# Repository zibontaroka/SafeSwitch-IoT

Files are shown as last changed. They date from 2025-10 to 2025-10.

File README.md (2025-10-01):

# ⚡ SafeSwitch-IoT: A Secure IoT-Based Control Handover System for Power Line Maintenance

  
  
  
  

This repository contains the full implementation of an **IoT-based Smart Power Control Handover System** that enhances **lineman safety** in power distribution networks.  
The system introduces a **formalized handover protocol** where Operators can delegate control of electrical zones/feeders to Linemen, ensuring safe maintenance by preventing accidental re-energization.

---

## 📑 Table of Contents
- [Overview](#-overview)
- [Key Features](#-key-features)
- [Technology Stack](#️-technology-stack)
- [Hardware and PCB Design](#-hardware-and-pcb-design)
- [File Structure](#-file-structure)
- [Getting Started](#-getting-started)
- [Usage](#-usage)
- [Contributing](#-contributing)
- [License](#-license)
- [Contact](#-contact)

---

## 📖 Overview
Power line maintenance is inherently dangerous, particularly in developing regions such as **Bangladesh**, where standardized safeguards are limited.  
One major risk arises when Operators unintentionally re-energize lines under maintenance, causing **severe injury or fatality** for Linemen.  

✅ Our proposed solution:  
A **secure IoT-based control handover system** that ensures Operators **cannot switch relays** in a zone once it is handed over to a Lineman.  
Control is restored only after the Lineman safely revokes access via a **PIN-authenticated interface**.

---

## ✨ Key Features
- 🔐 **Secure Control Handover** – Operator-to-Lineman delegation with mutual exclusion.  
- 👤 **Role-Based Access Control (RBAC)** – Enforces permissions per role.  
- ⚡ **Real-Time Communication** – WebSocket-based low-latency updates.  
- 🔑 **PIN-Based Authentication** – Prevents unauthorized relay operations.  
- 📝 **Auditability & Traceability** – Logs every critical action with user ID, timestamp, feeder/zone.  
- 📈 **Modular & Scalable** – Easily extendable for more devices/zones.  

---

## ⚙️ Technology Stack
**Backend:** Node.js · Express.js · PostgreSQL · WebSocket  
**Frontend:** HTML · CSS · JavaScript  
**Hardware:** ESP8266 · LM2596 Buck Converter · 2N2222 NPN Transistor · 1N4007 Diode · Relays  

---

## 🖥️ Web Application Interface

### Operator Dashboard
Centralized control center for system operators to monitor and manage power distribution network.

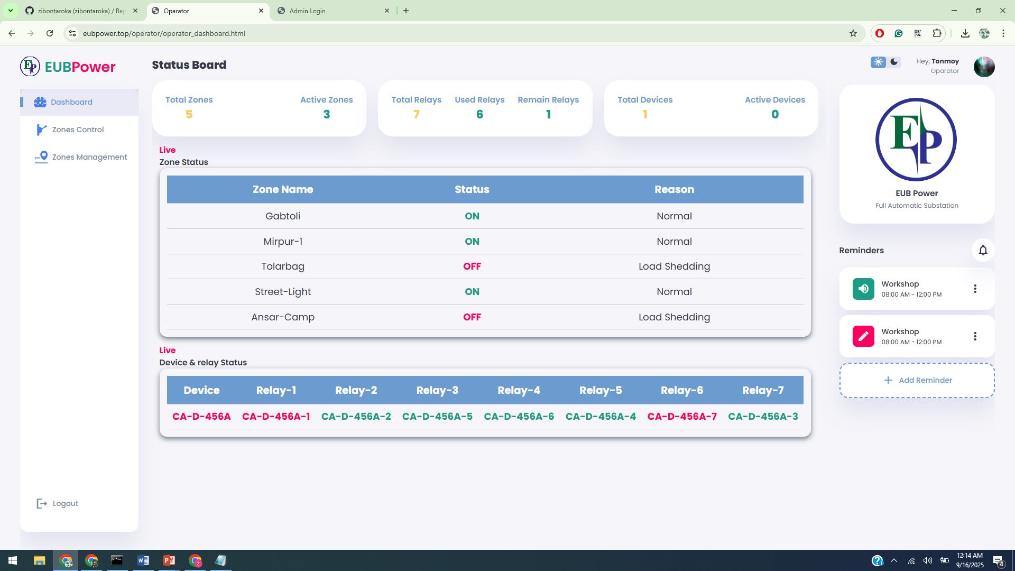
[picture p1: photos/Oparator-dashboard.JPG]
Operator Dashboard


**Key Functionalities:**
- 📊 **Real-time Monitoring** - Live status of all feeders and zones
- 🔄 **Control Handover** - Safe delegation to linemen for maintenance
- 🚨 **Emergency Override** - Critical situation management
- 📈 **System Analytics** - Performance metrics and usage statistics
- 👥 **User Management** - Lineman assignment and role management

**Interface Components:**
1. **Sidebar Navigation** - Quick access to different sections
2. **Dashboard Overview** - System-wide status at a glance  
3. **Feeder Control Panel** - Individual zone management
4. **Handover History** - Audit trail of all control transfers
5. **Alert System** - Real-time notifications and warnings

### Lineman Dashboard
Secure, PIN-protected interface for field technicians during maintenance operations.

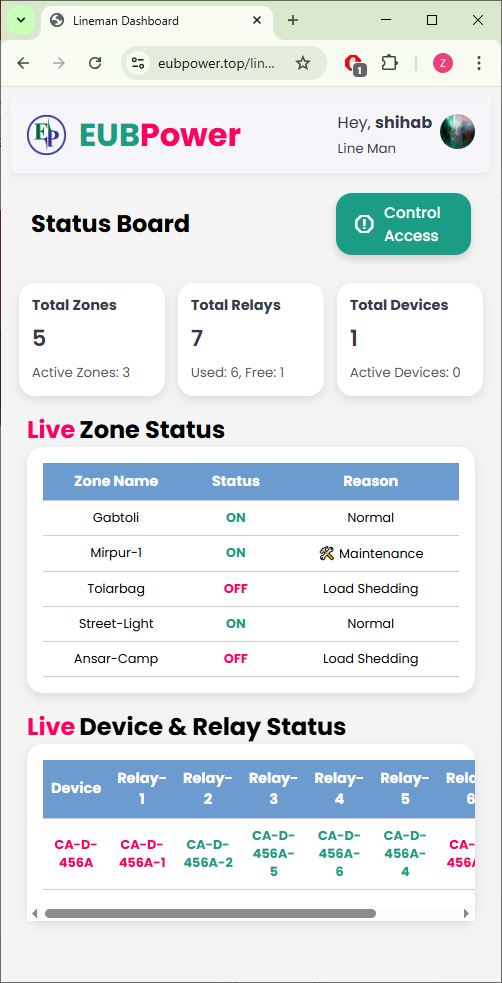
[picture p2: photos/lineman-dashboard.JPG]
Lineman Dashboard


**Key Functionalities:**
- 🔐 **PIN Authentication** - Secure access to assigned zones
- ⚡ **Relay Control** - Direct control over circuit breakers
- 📱 **Mobile-Friendly** - Optimized for field use
- 🔄 **Status Sync** - Real-time synchronization with backend
- ✅ **Safety Lock** - Prevents accidental operations

**Security Features:**
- Session timeout after inactivity
- PIN-based re-authentication required
- Control limited to assigned zones only
- Audit log of all operations
- Emergency stop functionality

### Workflow Demonstration
**Control Handover Process:**
1. Operator initiates handover from their dashboard
2. Lineman receives notification and enters PIN
3. Control transfers to lineman (operator access locked)
4. Lineman performs maintenance operations
5. Lineman revokes control after completion
6. Operator regains full control automatically

---

## 🔧 Hardware and PCB Design

The **ESP8266 control module** manages up to **7 relays** for breaker/switch control.  
It authenticates with the backend and executes Operator/Lineman commands securely.  

### Relay Control Module
- Authentication with backend  
- Relay switching via GPIO  
- Real-time state reporting  

**Schematic Diagram:**  
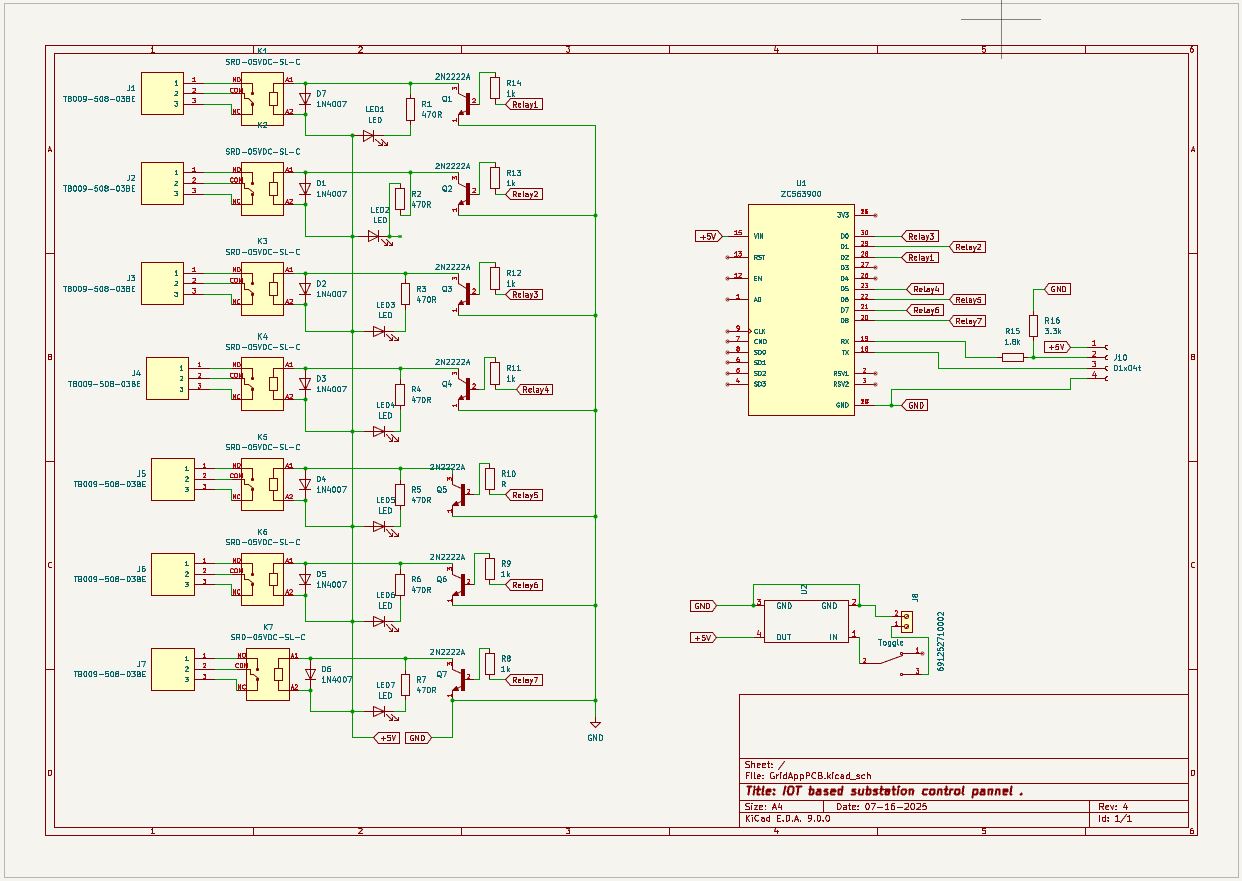
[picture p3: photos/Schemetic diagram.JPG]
Schematic Diagram
  

**PCB Layout:**  
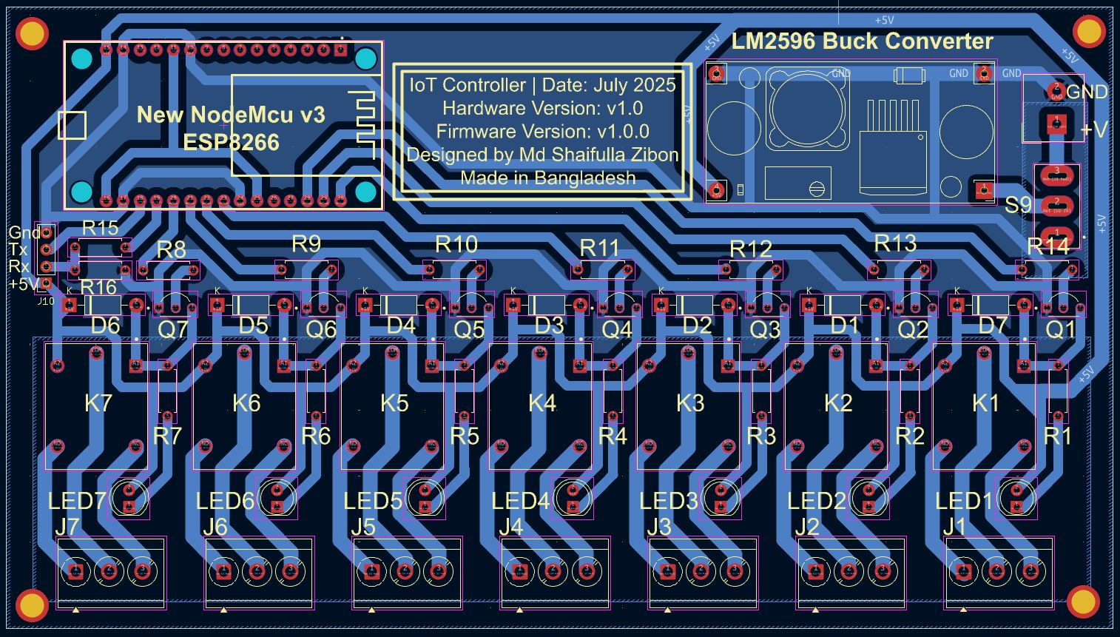
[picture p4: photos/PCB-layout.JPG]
PCB Layout
  

🔗 KiCad project & Gerber files are in the [`PCB_design/`](./PCB_design/) directory.  

---

## 📂 File Structure
```

smart-power-handover-system/
├── database/        # PostgreSQL backup (powergrid\_backup.sql)
├── firmware/        # ESP8266 Arduino firmware
├── PCB\_design/      # Hardware design (KiCad + Gerber)
├── photos/          # PCB & schematic images
├── web\_app/         # Web application (frontend + backend)
├── admin/       # Admin dashboard & user management
├── operator/    # Operator control dashboard
├── lineman/     # Lineman PIN-secured dashboard
├── viewer/      # Viewer-only monitoring UI
├── backend/     # Node.js backend (Express + WebSocket)
├── css/         # Stylesheets
├── js/          # Frontend JS logic
└── images/      # UI assets/icons

```

---

## 🚀 Getting Started

### Prerequisites
- [Node.js](https://nodejs.org/) (>= 18.x)  
- [PostgreSQL](https://www.postgresql.org/)  

### Installation

1. **Clone the repository:**
   ```bash
   git clone https://github.com/zibontaroka/SafeSwitch-IoT.git
   cd smart-power-handover-system/web_app/backend
   ```

2. **Install dependencies:**
   ```bash
   npm install
   ```

3. **Set up the database:**
   - Create a PostgreSQL database
   - Import the backup:
     ```bash
     psql -U your_user -d your_db -f ../../database/powergrid_backup.sql
     ```

4. **Configure environment variables:**
   Create `.env` file in `web_app/backend/` directory with:
   ```env
   DB_USER=your_db_user
   DB_HOST=your_db_host
   DB_DATABASE=your_db_name
   DB_PASSWORD=your_db_password
   DB_PORT=your_db_port
   JWT_SECRET=your_jwt_secret
   ```

5. **Start the server:**
   ```bash
   npm start
   ```

---

## 📖 Usage (Control Workflow)

1. **Initiation** → Operator selects feeder/zone & assigns to a Lineman.
2. **Delegation** → Zone marked as `control_active = TRUE`, blocking Operator actions.
3. **Execution** → Lineman controls relays via PIN-authenticated dashboard.
4. **Revocation** → Lineman revokes control (PIN entry → `control_active = FALSE`).
5. **Restoration** → Operator regains full control.

---

## 🤝 Contributing

Contributions, feature requests, and bug reports are welcome!
Please open an **issue** or submit a **pull request**.

---

## 📄 License

This project currently has **no license**.
(You may add `MIT`, `Apache-2.0`, or another license in a [LICENSE](LICENSE) file.)

---

## 📞 Contact

📧 Md Shaifulla Zibon
🔗 [LinkedIn](https://www.linkedin.com/in/md-shaifulla-zibon/)

---

"# SafeSwitch-IoT"

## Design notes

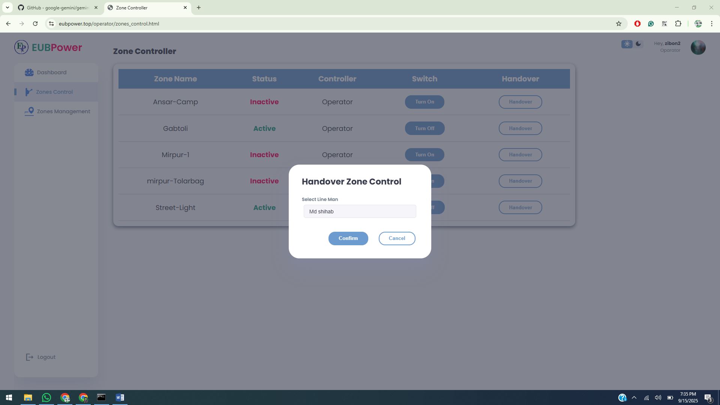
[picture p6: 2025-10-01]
photos/Zone controll and handover page.JPG

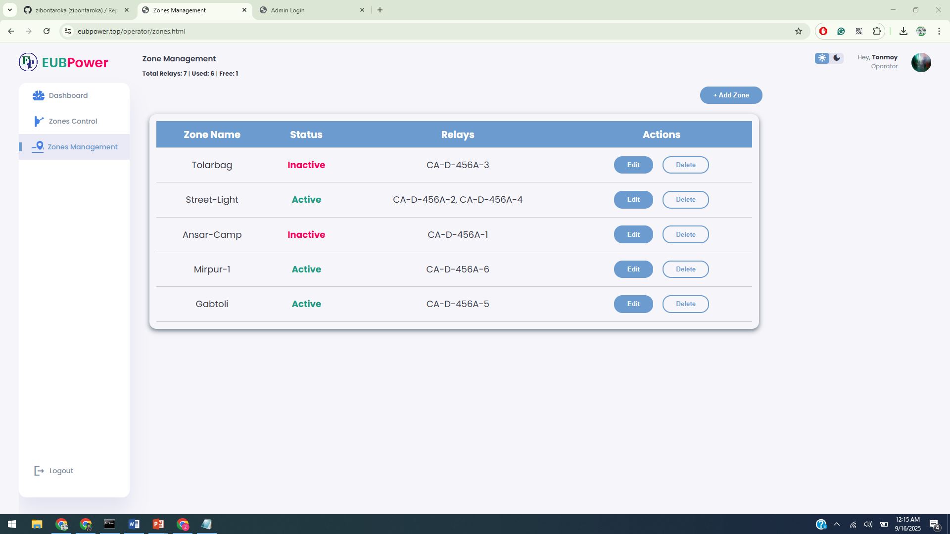
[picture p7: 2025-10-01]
photos/Oparator-zone-management.JPG

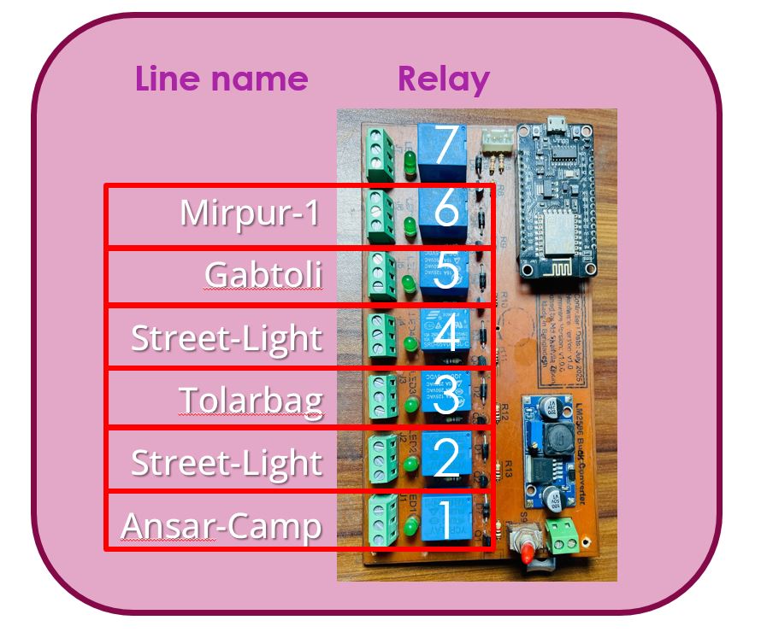
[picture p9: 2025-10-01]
photos/relay and zone configuration.JPG

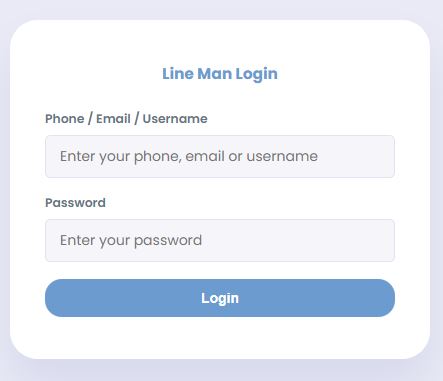
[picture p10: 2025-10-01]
photos/login.JPG

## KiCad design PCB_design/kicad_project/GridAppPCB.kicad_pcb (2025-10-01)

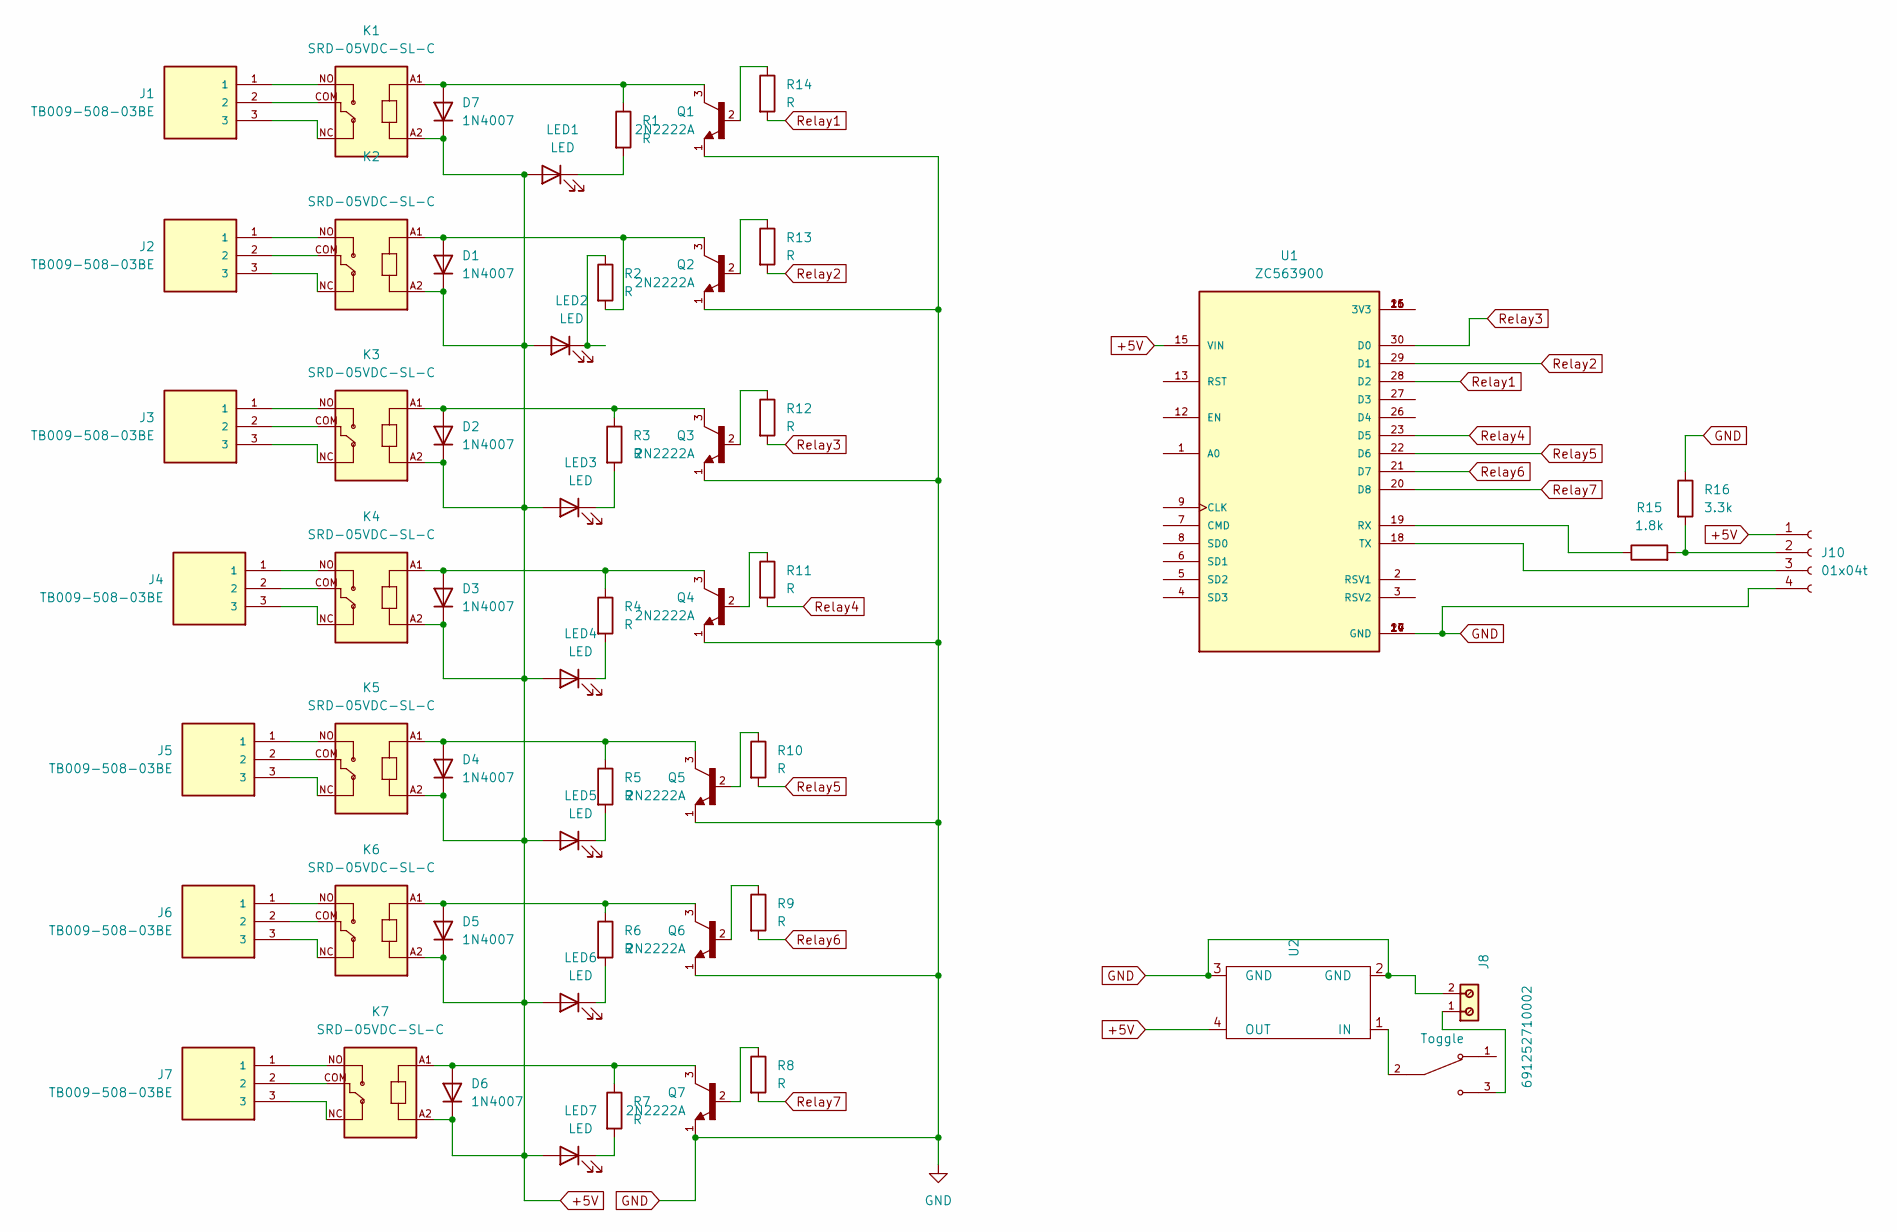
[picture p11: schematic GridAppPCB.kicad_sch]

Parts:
D1, D2, D3, D4, D5, D6, D7: 1N4007; D_DO-41_SOD81_P10.16mm_Horizontal
J1, J2, J3, J4, J5, J6, J7: TB009-508-03BE; TerminalBlock_CUI_TB007-508-03_1x03_P5.08mm_Horizontal
J8: 691252710002; Altech_AK100_1x02_P5.00mm; PART-NUMBER 691252710002
J10: 01x04t; PinSocket_1x04_P2.54mm_Vertical
K1, K2, K3, K4, K5, K6, K7: SRD-05VDC-SL-C; RELAY_SRD-05VDC-SL-C
LED1, LED2, LED3, LED4, LED5, LED6, LED7: LED; LED_D5.0mm
Q1, Q2, Q3, Q4, Q5, Q6, Q7: 2N2222A; TO92254P470H750-3; PARTREV N/A
R1, R2, R3, R4, R5, R6, R7, R8, R9, R10, R11, R12, R13, R14: R; R_Axial_DIN0207_L6.3mm_D2.5mm_P7.62mm_Horizontal
R15: 1.8k; R_Axial_DIN0207_L6.3mm_D2.5mm_P7.62mm_Horizontal
R16: 3.3k; R_Axial_DIN0207_L6.3mm_D2.5mm_P7.62mm_Horizontal
S9: Toggle; SW_100SP1T1B1M1QEH; PARTREV D
U1: ZC563900; MODULE_ZC563900; PARTREV 1.0
U2: YAAJ_DCDC_StepDown_LM2596

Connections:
+5V: D1.1 (K), D2.1 (K), D3.1 (K), D4.1 (K), D5.1 (K), D6.1 (K), D7.1 (K), J10.1, K1.A2, K2.A2, K3.A2, K4.A2, K5.A2, K6.A2, K7.A2, LED1.2 (A), LED2.2 (A), LED3.2 (A), LED4.2 (A), LED5.2 (A), LED6.2 (A), LED7.2 (A), U1.15 (VIN), U2.4 (OUT)
GND: J8.2, J10.4, Q1.1, Q2.1, Q3.1, Q4.1, Q5.1, Q6.1, Q7.1, R16.1, U1.10 (GND), U1.14 (GND), U1.17 (GND), U1.24 (GND), U2.2 (GND), U2.3 (GND)
unnamed: D1.2 (A), K2.A1, Q2.3, R2.2
unnamed: D2.2 (A), K3.A1, Q3.3, R3.1
unnamed: D3.2 (A), K4.A1, Q4.3, R4.1
unnamed: D4.2 (A), K5.A1, Q5.3, R5.1
unnamed: D5.2 (A), K6.A1, Q6.3, R6.1
unnamed: D6.2 (A), K7.A1, Q7.3, R7.1
unnamed: D7.2 (A), K1.A1, Q1.3, R1.1
unnamed: J1.1, K1.NO
unnamed: J1.2, K1.COM
unnamed: J1.3, K1.NC
unnamed: J2.1, K2.NO
unnamed: J2.2, K2.COM
unnamed: J2.3, K2.NC
unnamed: J3.1, K3.NO
unnamed: J3.2, K3.COM
unnamed: J3.3, K3.NC
unnamed: J4.1, K4.NO
unnamed: J4.2, K4.COM
unnamed: J4.3, K4.NC
unnamed: J5.1, K5.NO
unnamed: J5.2, K5.COM
unnamed: J5.3, K5.NC
unnamed: J6.1, K6.NO
unnamed: J6.2, K6.COM
unnamed: J6.3, K6.NC
unnamed: J7.1, K7.NO
unnamed: J7.2, K7.COM
unnamed: J7.3, K7.NC
unnamed: J8.1, S9.3
unnamed: J10.2, R15.2, R16.2
unnamed: J10.3, U1.18 (TX)
unnamed: LED1.1 (K), R1.2
unnamed: LED2.1 (K), R2.1
unnamed: LED3.1 (K), R3.2
unnamed: LED4.1 (K), R4.2
unnamed: LED5.1 (K), R5.2
unnamed: LED6.1 (K), R6.2
unnamed: LED7.1 (K), R7.2
unnamed: Q1.2, R14.1
unnamed: Q2.2, R13.1
unnamed: Q3.2, R12.1
unnamed: Q4.2, R11.1
unnamed: Q5.2, R10.1
unnamed: Q6.2, R9.1
unnamed: Q7.2, R8.1
unnamed: U1.11 (3V3), U1.16 (3V3), U1.25 (3V3)
unnamed: R15.1, U1.19 (RX)
unnamed: S9.2, U2.1 (IN)
Relay1: R14.2, U1.28 (D2)
Relay2: R13.2, U1.29 (D1)
Relay3: R12.2, U1.30 (D0)
Relay4: R11.2, U1.23 (D5)
Relay5: R10.2, U1.22 (D6)
Relay6: R9.2, U1.21 (D7)
Relay7: R8.2, U1.20 (D8)

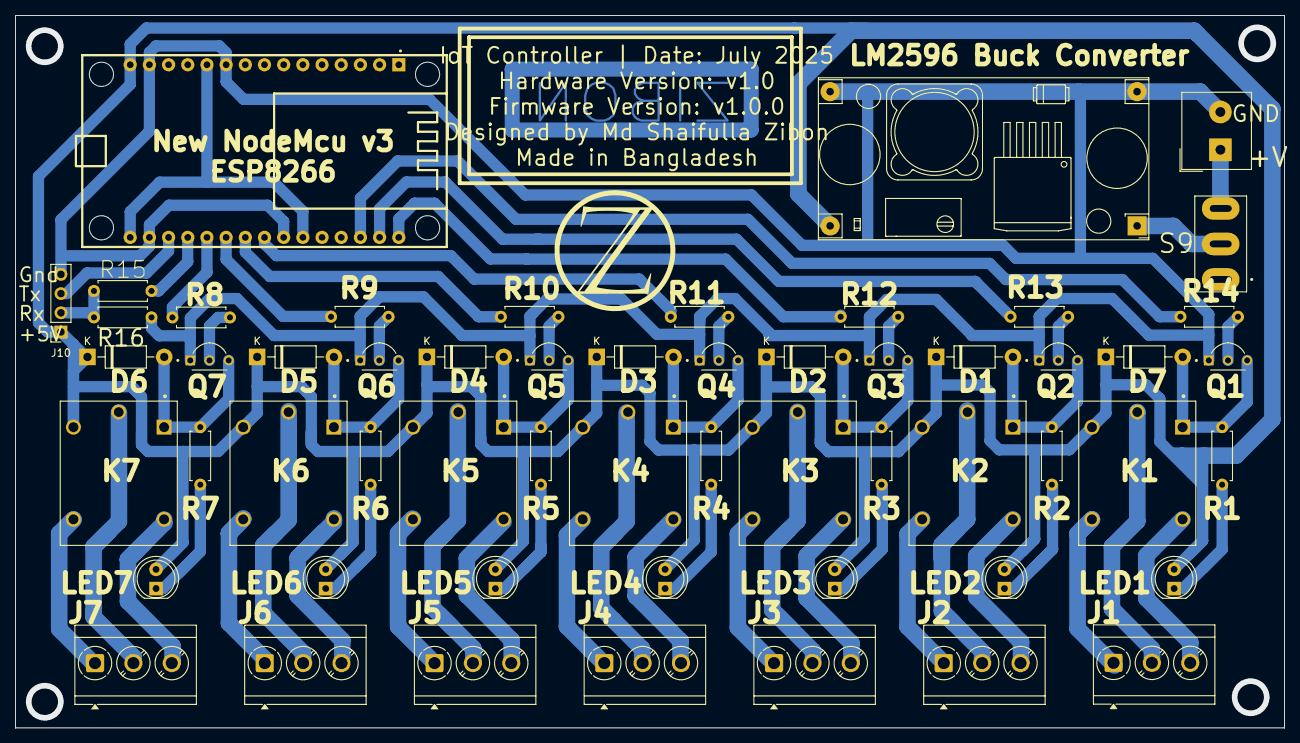
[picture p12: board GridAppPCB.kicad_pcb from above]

Board: 2 copper layers, 168.0 x 94.3 mm, 56 parts (0 on the bottom side), 57 nets.

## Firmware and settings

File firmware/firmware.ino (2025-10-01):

#include <ESP8266WiFi.h>
#include <WebSocketsClient.h>
#include <ArduinoJson.h>

// WiFi Credentials
const char* ssid = "Boroloks Squad";
const char* password = "1234abcde";

// Server Config
const char* websocket_host = "eubpower.top";
const uint16_t websocket_port = 3010;      
const char* websocket_path = "/ws";  

// Device Identity
const char* secret_key = "sMpsIoT@9876euytfhfkf";
const char* device_code = "CA-D-456A";

// WebSocket Client
WebSocketsClient webSocket;

// Relay GPIO pins
const int relayPins[7] = {4, 5, 16, 14, 12, 13, 15};
bool relayStates[7] = {false, false, false, false, false, false, false};

// Send relay update for a single relay to server
void sendRelayUpdate(int index, bool state) {
  StaticJsonDocument<256> doc;
  doc["type"] = "relay_update";
  doc["relay_uid"] = String(device_code) + "-" + String(index + 1);
  doc["status"] = state;

  String out;
  serializeJson(doc, out);
  webSocket.sendTXT(out);
  Serial.print("📤 Relay Update Sent → ");
  Serial.println(out);
}

// Send full relay status report after auth_ok from server
void sendRelayStatusReport() {
  StaticJsonDocument<512> report;
  report["type"] = "relay_status_report";
  JsonArray arr = report.createNestedArray("states");

  for (int i = 0; i < 7; i++) {
    JsonObject obj = arr.createNestedObject();
    obj["relay_uid"] = String(device_code) + "-" + String(i + 1);
    obj["status"] = relayStates[i];
  }

  String out;
  serializeJson(report, out);
  webSocket.sendTXT(out);
  Serial.println("📤 Sent relay_status_report");
}

// Apply relay state physically and update relayStates array (no server update)
void applyRelayState(int index, bool state) {
  digitalWrite(relayPins[index], state ? HIGH : LOW);
  relayStates[index] = state;
  Serial.printf("🔧 Relay %d set to %s\n", index + 1, state ? "ON" : "OFF");
}

// Parse relay index from relay UID string like "CA-D-456A-3"
int relayUidToIndex(const char* relay_uid) {
  String relayUIDStr = String(relay_uid);
  int lastDash = relayUIDStr.lastIndexOf('-');
  if (lastDash == -1) return -1;
  String idxStr = relayUIDStr.substring(lastDash + 1);
  int relayIndex = idxStr.toInt() - 1;
  if (relayIndex < 0 || relayIndex >= 7) return -1;
  return relayIndex;
}

// Handle relay_command from server to update relay states
void handleRelayCommand(const JsonObject& obj) {
  if (!obj.containsKey("relay_uid") || !obj.containsKey("status")) {
    Serial.println("⚠️ relay_command missing fields");
    return;
  }

  const char* relay_uid = obj["relay_uid"];
  bool status = obj["status"];

  int relayIndex = relayUidToIndex(relay_uid);
  if (relayIndex == -1) {
    Serial.println("⚠️ Relay index invalid or out of range");
    return;
  }

  if (relayStates[relayIndex] != status) {
    applyRelayState(relayIndex, status);
  } else {
    Serial.println("ℹ️ Relay state already matches command");
  }
}

// WebSocket event handler
void webSocketEvent(WStype_t type, uint8_t * payload, size_t length) {
  switch(type) {
    case WStype_CONNECTED:
      Serial.println("✅ WebSocket connected");

      {
        StaticJsonDocument<256> doc;
        doc["type"] = "auth";
        doc["secret"] = secret_key;
        doc["device_code"] = device_code;

        String out;
        serializeJson(doc, out);
        webSocket.sendTXT(out);
        Serial.println("📤 Auth sent");
      }
      break;

    case WStype_DISCONNECTED:
      Serial.println("🔌 WebSocket disconnected");
      break;

    case WStype_TEXT:
      Serial.printf("📩 Message: %s\n", payload);

      {
        StaticJsonDocument<512> doc;
        DeserializationError error = deserializeJson(doc, payload, length);
        if (!error) {
          const char* msgType = doc["type"];
          if (!msgType) return;

          if (strcmp(msgType, "auth_ok") == 0) {
            sendRelayStatusReport();
          } else if (strcmp(msgType, "relay_command") == 0) {
            handleRelayCommand(doc.as<JsonObject>());
          }
        } else {
          Serial.println("⚠️ JSON parse error in incoming message");
        }
      }
      break;

    case WStype_ERROR:
      Serial.println("❌ WebSocket error");
      break;

    default:
      break;
  }
}

// Connect to WiFi with serial status output
void connectToWiFi() {
  Serial.printf("🔗 Connecting to %s...\n", ssid);
  WiFi.begin(ssid, password);
  while (WiFi.status() != WL_CONNECTED) {
    delay(500);
    Serial.print(".");
  }
  Serial.println("\n✅ WiFi connected!");
  Serial.print("📡 IP: ");
  Serial.println(WiFi.localIP());
}

// Handle manual serial input (e.g. "1010111")
void handleSerialInput(String input) {
  input.trim();

  if (input.length() != 7) {
    Serial.println("⚠️ Invalid input length! Use 7-digit binary like 1010111");
    return;
  }

  for (int i = 0; i < 7; i++) {
    char c = input.charAt(i);
    if (c != '0' && c != '1') {
      Serial.println("⚠️ Invalid character! Use only 0 or 1");
      return;
    }
  }

  // Apply new states and send update if changed
  for (int i = 0; i < 7; i++) {
    bool newState = input.charAt(i) == '1';
    if (relayStates[i] != newState) {
      applyRelayState(i, newState);
      sendRelayUpdate(i, newState);
    }
  }

  Serial.print("✅ Updated Relay States: ");
  Serial.println(input);
}

void setup() {
  Serial.begin(115200);
  // Initialize relay pins to LOW and internal state false
  for (int i = 0; i < 7; i++) {
    pinMode(relayPins[i], OUTPUT);
    digitalWrite(relayPins[i], LOW);
    relayStates[i] = false;
  }

  connectToWiFi();

  webSocket.begin(websocket_host, websocket_port, websocket_path);
  webSocket.onEvent(webSocketEvent);
  webSocket.setReconnectInterval(5000);

  Serial.println("📥 Type 7-digit relay pattern like: 1010111");
}

void loop() {
  webSocket.loop();

  if (Serial.available()) {
    String input = Serial.readStringUntil('\n');
    handleSerialInput(input);
  }
}

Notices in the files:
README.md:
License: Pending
